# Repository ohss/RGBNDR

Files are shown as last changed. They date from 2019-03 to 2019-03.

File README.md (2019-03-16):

# RGBNDR

RGBNDR is a video synthesiser made by circuit bending a VGA test generator. Inspired by [CHA/V by Jonas Bers](https://jonasbers.com/chav/).

RGBNDR is currently a set of two PCB:s. A board for circuit bending a VGA signal and a board for generating nice signals for bending video. It's a modular design so new boards can be easily added later.

Here's some instructions about how to build one. Schematics, eagle files and gerbers for manufacturing can be found form [https://github.com/ohss/RGBNDR](https://github.com/ohss/RGBNDR)

You can find some examples about what you can do with one on Instagram: [https://www.instagram.com/explore/tags/rgbndr/](https://www.instagram.com/explore/tags/rgbndr/) or you can check out the video below:

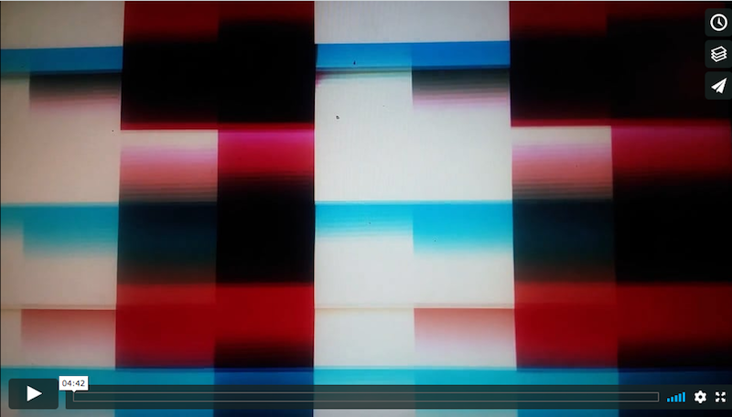
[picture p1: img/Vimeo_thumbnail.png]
RGBNDR Video Synth test on Vimeo (https://vimeo.com/258845977)


# Build it!



You will need to build two boards: RGBNDR board and Modulator board:

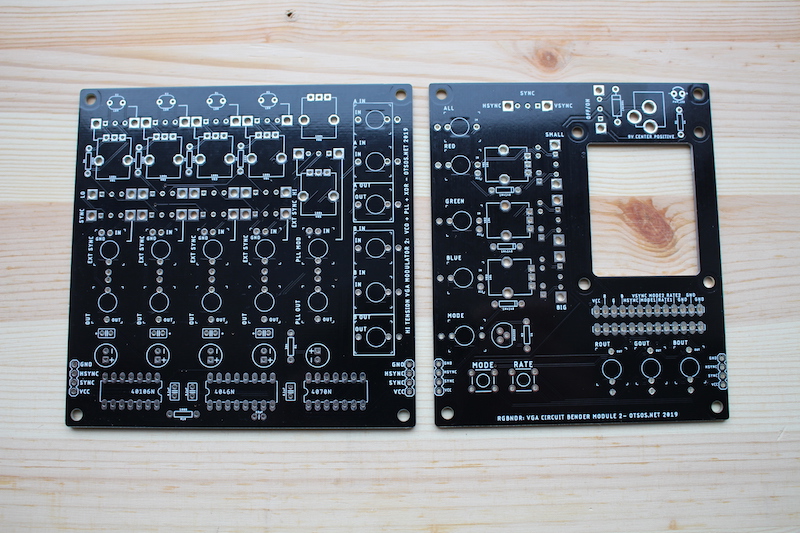
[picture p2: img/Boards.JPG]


Here's a RGBNDR board hooked up to two modulator boards:

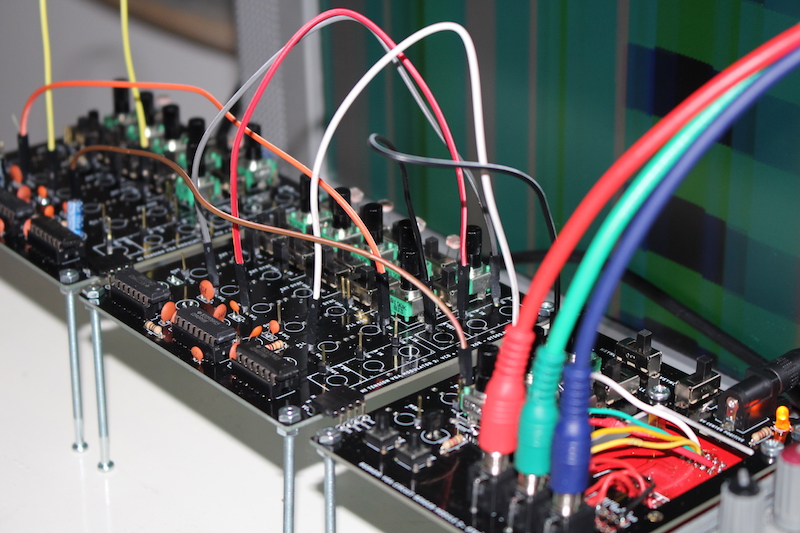
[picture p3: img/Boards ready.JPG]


Here's a quick tip on how to solder:

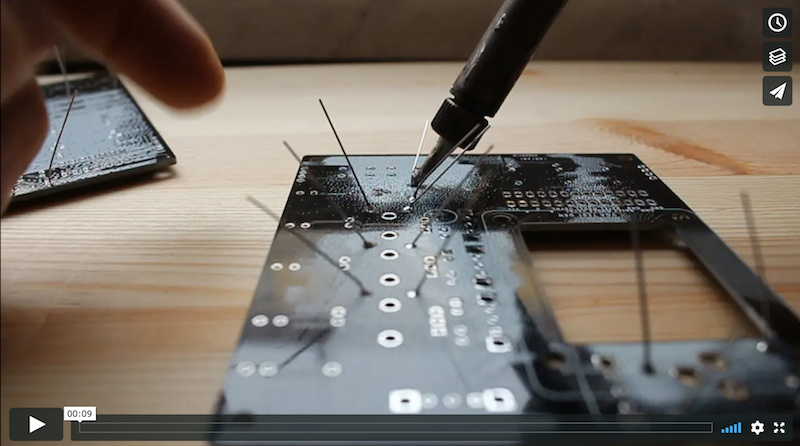
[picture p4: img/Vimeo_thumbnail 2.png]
How to solder (https://vimeo.com/324415428)


## Building RGBNDR (board with VGA test generator)

Here's what you'll need:

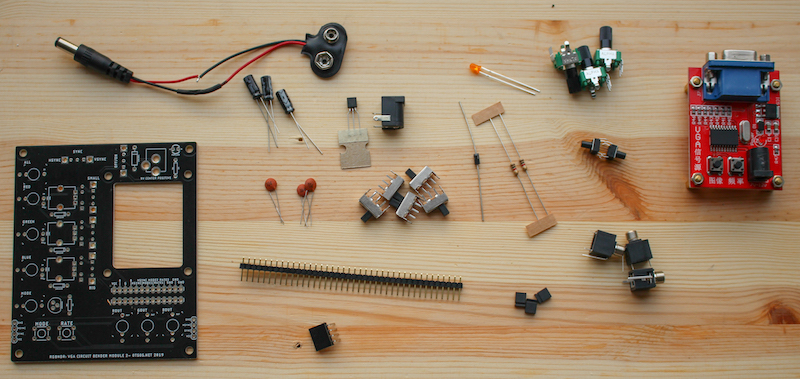
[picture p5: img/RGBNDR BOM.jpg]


| Num | Part | Val | Comment | Link |
|-----|---|-----|---|---|
|2x1|Male pin header||||			
|3x2|Male pin header||||			
|1x4|Female pin header|90° angle|||
|1|Led|3mm|||
|2|Pushbutton|MOMENTARY-SWITCH-SPST-PTH-6.0MM|||
|5|Slide switch|SLIDE SWITCH 1P2T THROUGH HOLE 0.5A 50VDC||https://www.taydaelectronics.com/slide-switch-1p2t-through-hole-0-5a-50vdc-2713.html|
|3|Ceramic capacitor|0.1uF (104)|Try out different values||
|3|Electrolytic capacitor|10uF|Try out different values. Remember polarity!||
|3|Potentiometer|10k|||
|1|Diode|1N4004|||
|3|Jumper wire||PCB has places for 1N4148 diodes. Use jumpers instead.||
|2|Resistor|1k|||
|1|Transistor|2N2222|Check polarity||
|1|Power Jack||V2 revision has a mistace on power. It's cCenter negative NOT center positive ||	
|3|Mono 3.5mm jack|Thonkiconn|Optional|https://www.thonk.co.uk/shop/3-5mm-jacks/|		

Start with adding caps to the bottom side. Remember to check polarity on electrolytic caps!

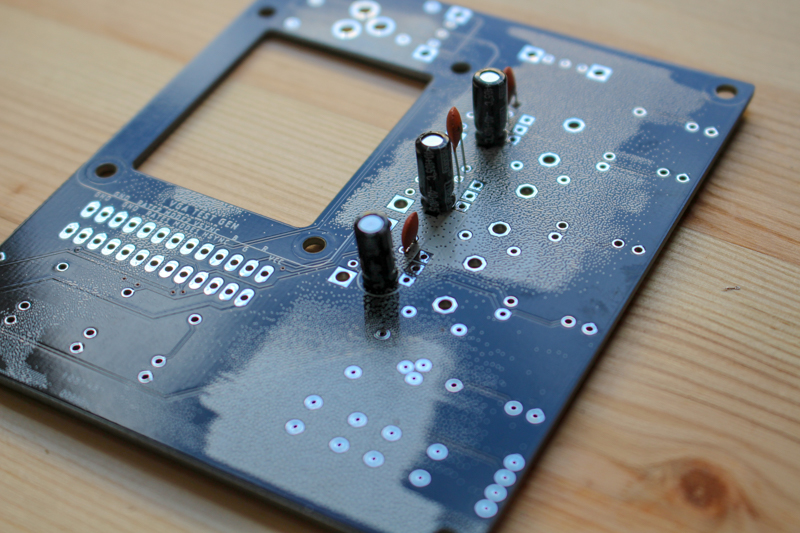
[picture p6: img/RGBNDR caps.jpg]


Use cap legs that you just cut out as jumpers. You'll need three. On the board there is three spots for 1N4148 diode. Use the jumpers instead.

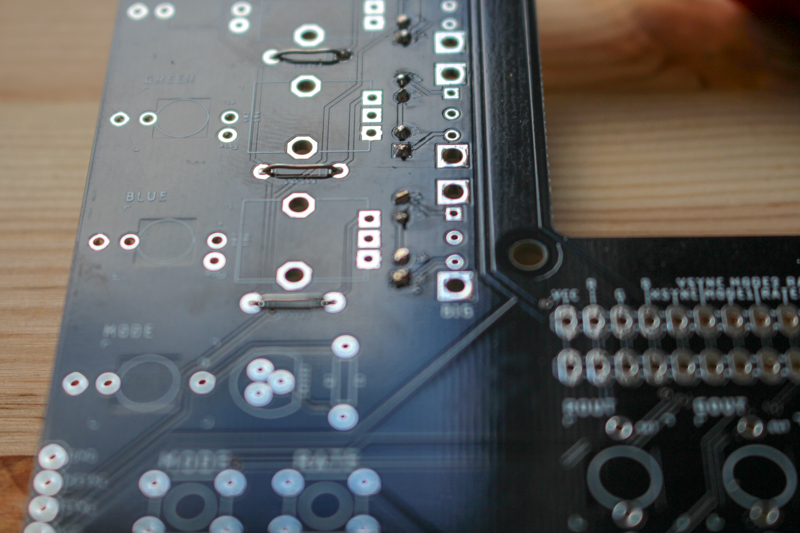
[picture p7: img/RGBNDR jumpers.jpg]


Add two 1k resistors and 1N4004 diode. Remember to check diode polarity!

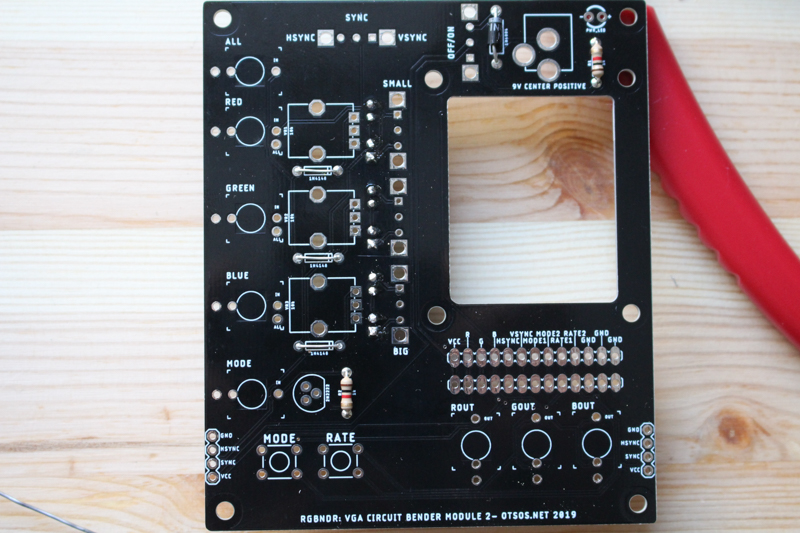
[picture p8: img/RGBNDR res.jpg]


Next one is a bit tricky. You'll need to solder header pins to the board. I like to place the header pins on the board, put a piece on cardboard on top of the pins and then flip the whole thing over with the cardboard keeping the pins where they should be. Usually they fall all over the place.

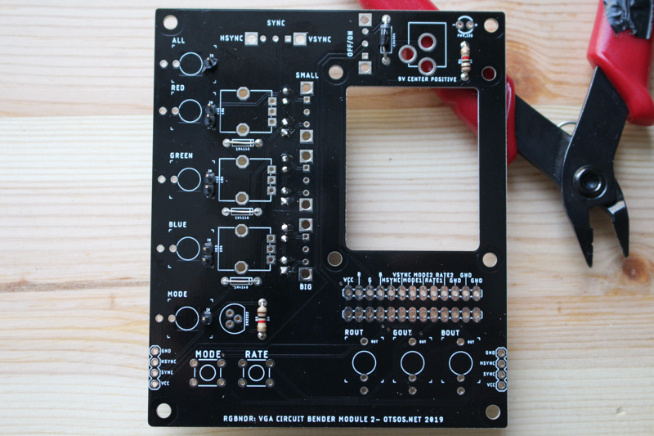
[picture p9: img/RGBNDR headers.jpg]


Then: pushbuttons, transistor (match the flat side to the flat line on the board ) and led. Long leg goes to +.

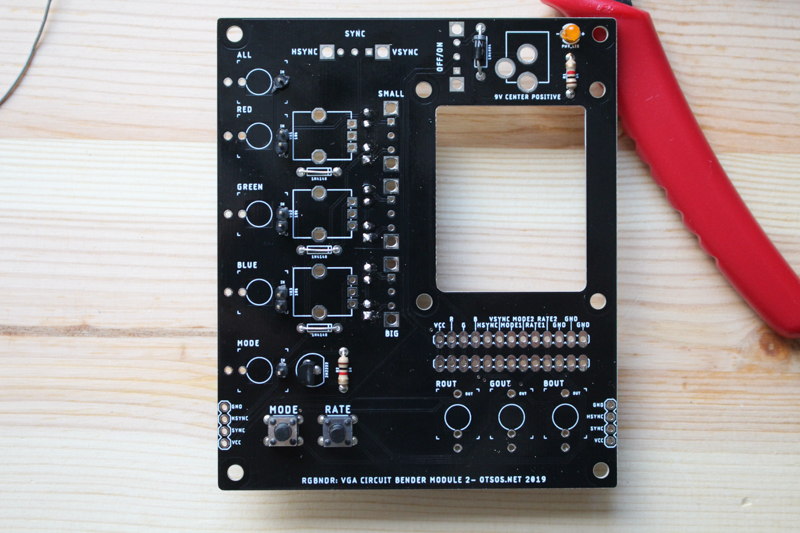
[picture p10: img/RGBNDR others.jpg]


Add female angle header for connecting with other board. Use a helping hand to get the angle header high enough:

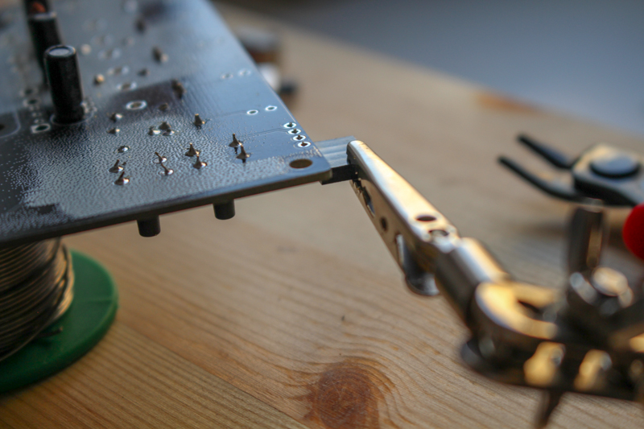
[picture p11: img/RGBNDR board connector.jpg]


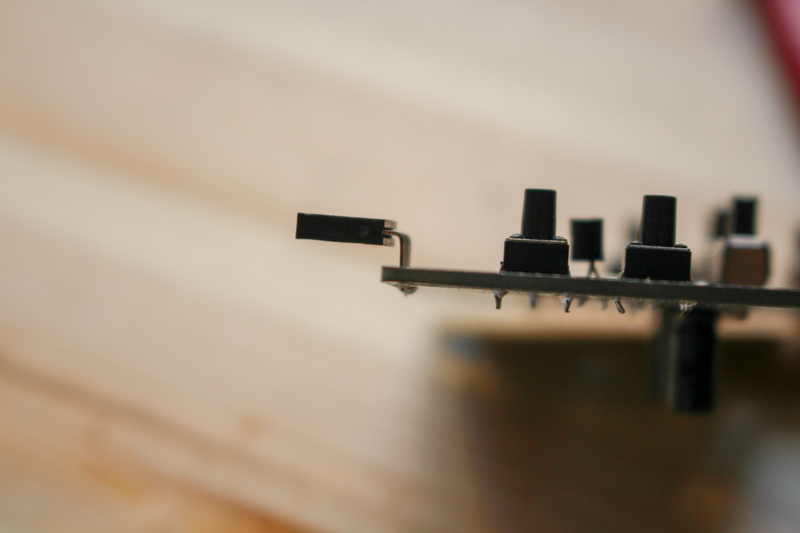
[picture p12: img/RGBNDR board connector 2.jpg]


Add (in this order): 5 slide switches, power connector, three 3.5mm mono jacks, three 10k potentiometers. For pots and slide switches it's ok to solder only the three middle pins.

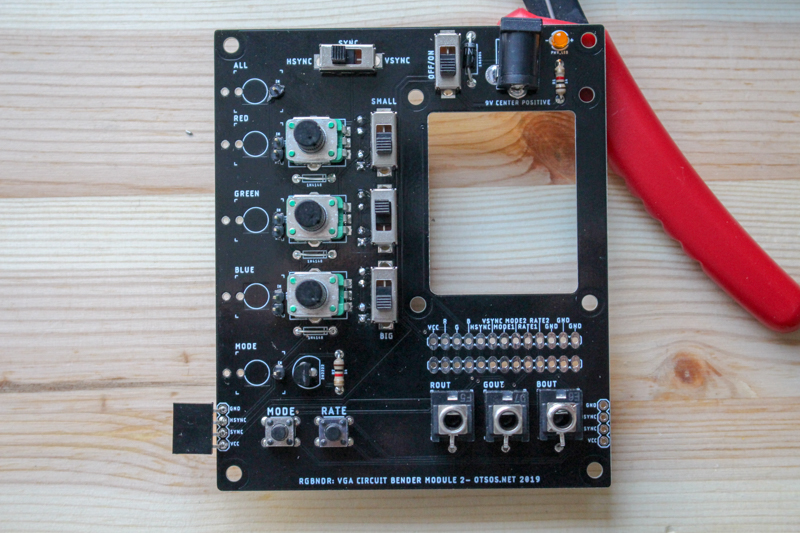
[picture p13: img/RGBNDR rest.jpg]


Solder wires from the test gen board to the RGBNDR board.

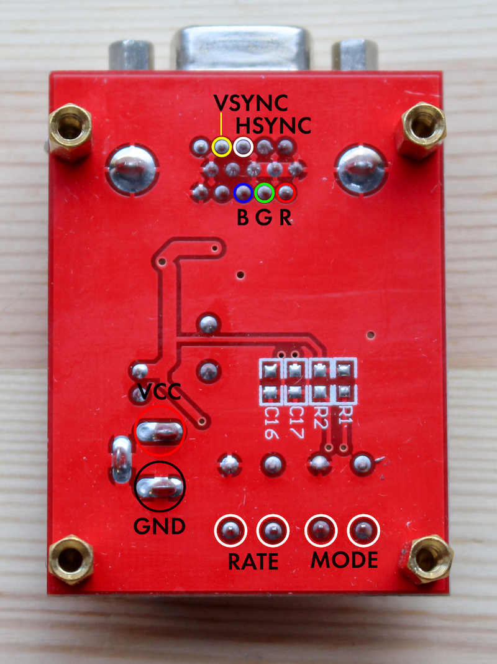
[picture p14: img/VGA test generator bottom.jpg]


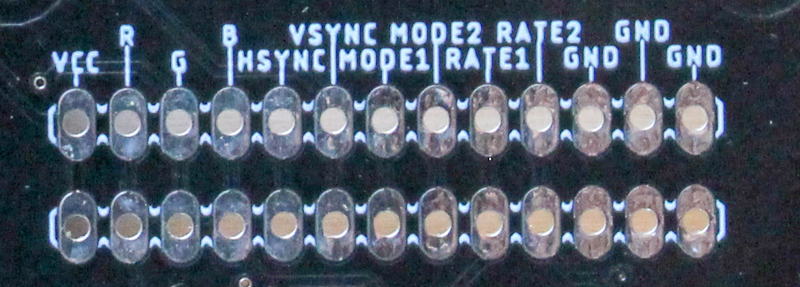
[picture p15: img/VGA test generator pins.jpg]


Done!

## Building modulator board

Here's what you'll need:

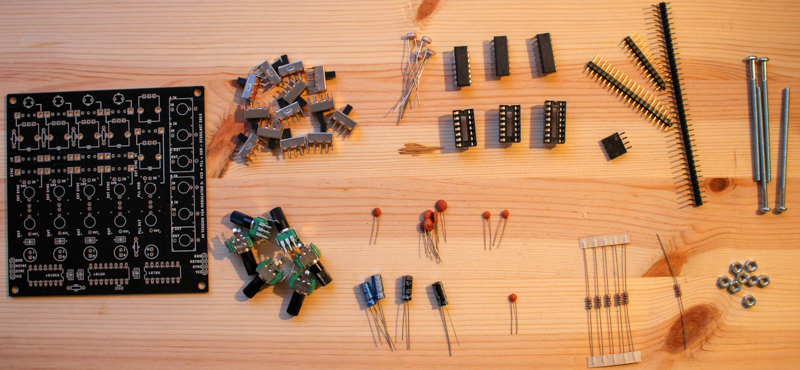
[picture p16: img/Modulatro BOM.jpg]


| Num | Part | Val | Comment | Link |
|-----|---|-----|---|---|
|11x1|Male pin header||||			
|5x2|Male pin header||||			
|1x4|Male pin header|90° angle|||
|4|LDR||Optional||
|13|Slide switch|SLIDE SWITCH 1P2T THROUGH HOLE 0.5A 50VDC|If you don't use LDRs, replace switch with jumper|https://www.taydaelectronics.com/slide-switch-1p2t-through-hole-0-5a-50vdc-2713.html|
|1|Ceramic capacitor|22pF||||
|1|Ceramic capacitor|0.001uF (102)|||
|2|Ceramic capacitor|0.01uF (103)|||
|5|Ceramic capacitor|0.1uF (104)|||
|2|Electrolytic capacitor|100uF|Remember polarity!||
|1|Electrolytic capacitor|10uF|Remember polarity!||
|1|Electrolytic capacitor|1uF|Remember polarity!||
|6|Potentiometer|100k|||
|1|Resistor|20k|||
|5|Resistor|100R|||
|1|IC|40106|||
|1|IC|4046|||
|1|IC|4070|||

Start with the flattest parts so that soldering is as easy as possible. So:

1. Resistors
2. ICs
3. Header pins
4. Caps
5. Switches
6. LDRs
7. Pots

Few tips:

Use IC sockets and align them correctly. I made a mistake on the photo:

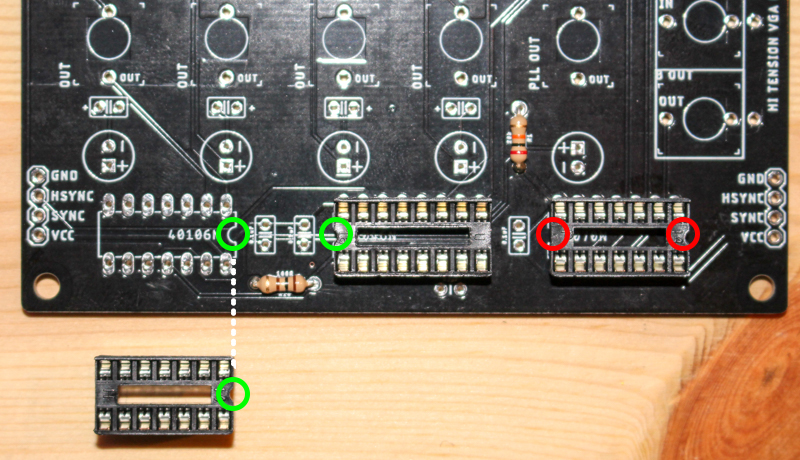
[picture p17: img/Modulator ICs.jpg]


You can chose what ever values for oscillator caps you want. Together with a potentiometer these will define frequency for an oscillator. For each oscillator you can pick big and small cap and change between those with a switch.

My setup is like this but try your own values!

| |OSC 1|OSC 2|OSC 3|OSC 4|4046 MOD|
|-----|-----|-----|-----|-----|---|
|SMALL|10nF|0.1nF|0.01nF|0.001nf| - |
| BIG |100nF|1nF|0.1nF|0.01nF|100nF|

I put the big caps on the bottom side.

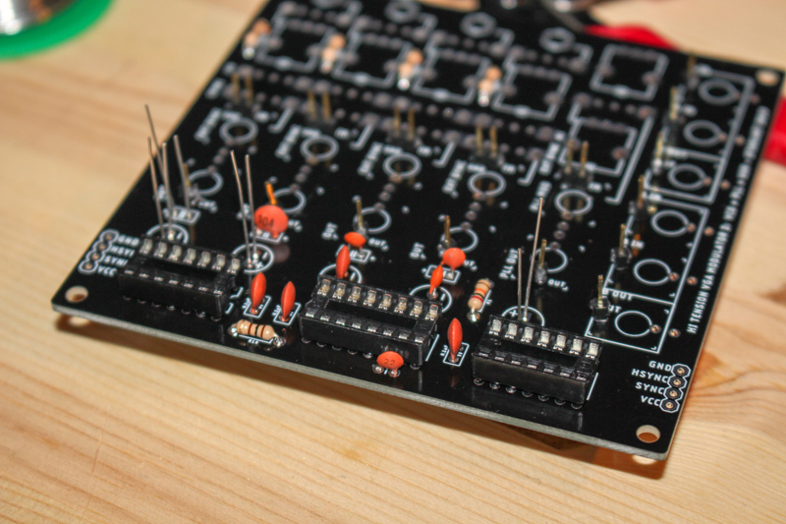
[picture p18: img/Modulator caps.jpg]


After some soldering it should look more or less like this:

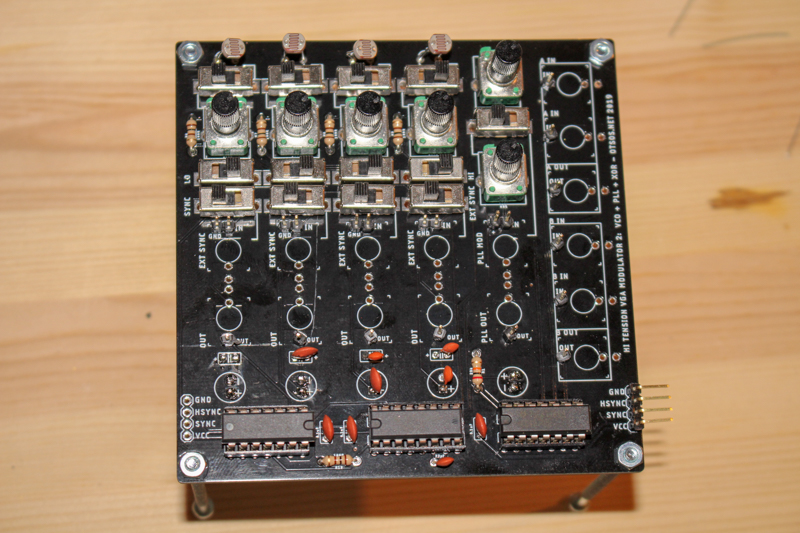
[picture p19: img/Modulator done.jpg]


Hook it up with RGBNDR and that's it!

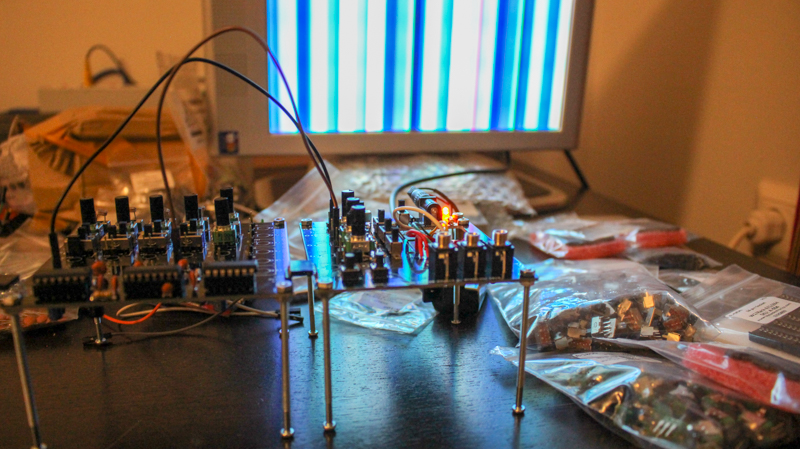
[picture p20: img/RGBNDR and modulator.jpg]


Later you can make a box for it. Here's an older version with jacks:

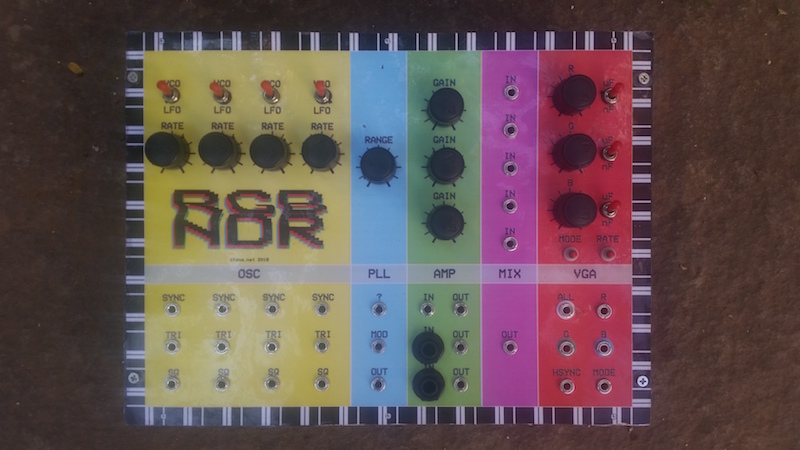
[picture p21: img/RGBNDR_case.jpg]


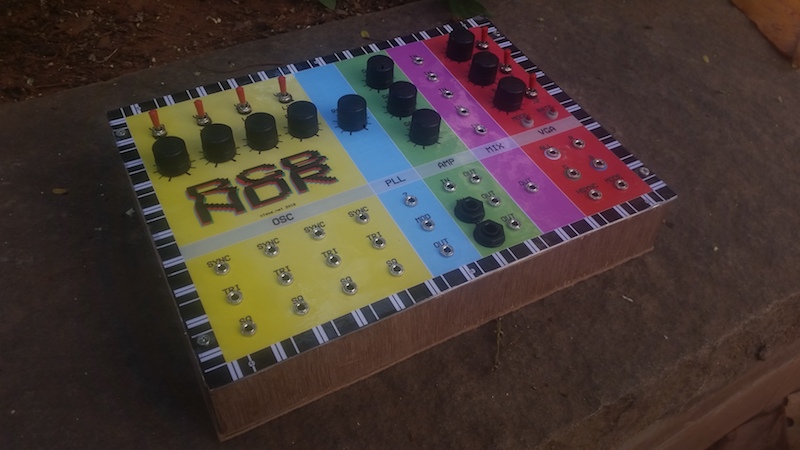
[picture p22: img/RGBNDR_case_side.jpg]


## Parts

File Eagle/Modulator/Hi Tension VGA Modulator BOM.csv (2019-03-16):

Qty | Value | Device | Package | Parts | Description | AVAILABILITY | DESCRIPTION | MF | MP | PACKAGE | PRICE | PROD_ID | SF_ID | SF_SKU | SPICEPREFIX | VALUE
5 |  | CONN_01PTH_NO_SILK_YES_STOP | 1X01_NO_SILK | J3, J4, J5, J6, J7 | Single connection point. Often used as Generic Header-pin footprint for 0.1 inch spaced/style header connections
2 |  | CONN_04 | 1X04 | J1, J8 | Multi connection point. Often used as Generic Header-pin footprint for 0.1 inch spaced/style header connections |  |  |  |  |  |  | CONN-09696
13 |  | OS102011MS2QN1 | SW_OS102011MS2QN1 | S1, S2, S3, S4, S5, S6, S7, S8, S9, S10, S11, S12, S13 | Switch Slide ON ON SPDT Top Slide 0.1A 12VDC 10000Cycles PC Pins Thru-Hole Bulk | Unavailable | Switch Slide ON ON SPDT Top Slide 0.1A 12VDC 10000Cycles PC Pins Thru-Hole Bulk | C&K | OS102011MS2QN1 | DO-201 C&amp | K Components | None
7 | 0.1uF | C-EU025-025X050 | C025-025X050 | C2, C4, C6, C8, C9, C12, C13 | CAPACITOR, European symbol |  |  |  |  |  |  |  |  |  | C
5 | 100R | 1KOHM-HORIZ-1/4W-1% | AXIAL-0.3 | R6, R7, R8, R9, R10 | 1kΩ resistor |  |  |  |  |  |  | RES-12182 |  |  |  | 1k
6 | 100k | POTENTIOMETER-PTH-9MM-1/20W-20% | POT-PTH-ALPS | VR1, VR2, VR3, VR4, VR5, VR6 | Potentiometer (Pot) |  |  |  |  |  |  | RES-09177 |  | COM-09288 |  | 10k
5 | 100uF | 100UF-POLAR-RADIAL-2.5MM-25V-20% | CPOL-RADIAL-2.5MM-6.5MM | C1, C3, C5, C7, C10 | 100µF polarized capacitors |  |  |  |  |  |  | CAP-08439 |  |  |  | 100uF
1 | 20k | 1KOHM-HORIZ-1/4W-1% | AXIAL-0.3 | R1 | 1kΩ resistor |  |  |  |  |  |  | RES-12182 |  |  |  | 1k
1 | 22pF | 22PF-PTH-2.54MM-200V-5% | CAP-PTH-2.54 | C11 | 22pF ceramic capacitors |  |  |  |  |  |  | CAP-09128 |  |  |  | 22pF
1 | 40106N | 40106N | DIL14 | IC1 | Hex SCHMITT TRIGGER
1 | 4046N | 4046N | DIL16 | IC2 | Micropower PLL
1 | 4070N | 4070N | DIL14 | IC3 | Quad 2-input XOR
4 | LDR | PHOTOCELLPTH | PHOTOCELL | R2, R3, R4, R5 | Photocell (Photodetector, Photo Resistor, CdS) |  |  |  |  |  |  | COMP-09129 | SEN-09088
16 | THONKICONNNEW | THONKICONNNEW | WQP-PJ301M-12_JACK | OSC1_OUT, OSC1_SYNC, OSC2_OUT, OSC2_SYNC, OSC3_OUT, OSC3_SYNC, OSC4_OUT, OSC4_SYNC, PLL_MOD, PLL_OUT, XOR_IN_1, XOR_IN_2, XOR_IN_3, XOR_IN_4, XOR_OUT_1, XOR_OUT_2 | 3.5mm socket for Eurorack modular synths

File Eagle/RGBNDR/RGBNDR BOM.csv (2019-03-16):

Qty | Value | Device | Package | Parts | Description | AVAILABILITY | DESCRIPTION | MF | MP | PACKAGE | PRICE | PROD_ID | SF_SKU | SPICEPREFIX | VALUE
3 |  | CONN_01PTH_NO_SILK_YES_STOP | 1X01_NO_SILK | ALL_J1, ALL_J2, ALL_J3 | Single connection point. Often used as Generic Header-pin footprint for 0.1 inch spaced/style header connections
2 |  | CONN_04 | 1X04 | J3, J6 | Multi connection point. Often used as Generic Header-pin footprint for 0.1 inch spaced/style header connections |  |  |  |  |  |  | CONN-09696
2 |  | CONN_13LONGPADS | 1X13-LONGPADS | J1, J2 | Multi connection point. Often used as Generic Header-pin footprint for 0.1 inch spaced/style header connections
1 |  | LED3MM | LED_3MM | PWR_LED | LED (Generic) |  |  |  |  |  |  | DIO-08794
2 |  | MOMENTARY-SWITCH-SPST-PTH-6.0MM | TACTILE_SWITCH_PTH_6.0MM | MODE_BTN, RATE_BTN | Momentary Switch (Pushbutton) - SPST |  |  |  |  |  |  | SWCH-08441 | COM-00097
5 |  | OS102011MS2QN1 | SW_OS102011MS2QN1 | OFF/ON, S1, S2, S3, S4 | Switch Slide ON ON SPDT Top Slide 0.1A 12VDC 10000Cycles PC Pins Thru-Hole Bulk | Unavailable | Switch Slide ON ON SPDT Top Slide 0.1A 12VDC 10000Cycles PC Pins Thru-Hole Bulk | C&K | OS102011MS2QN1 | DO-201 C&amp | K Components | None
3 | 0.1uF | C-EU025-025X050 | C025-025X050 | C1, C3, C5 | CAPACITOR, European symbol |  |  |  |  |  |  |  |  | C
3 | 100uF | 100UF-POLAR-RADIAL-2.5MM-25V-20% | CPOL-RADIAL-2.5MM-6.5MM | C2, C4, C6 | 100µF polarized capacitors |  |  |  |  |  |  | CAP-08439 |  |  | 100uF
3 | 10k | POTENTIOMETER-PTH-9MM-1/20W-20% | POT-PTH-ALPS | VR1, VR2, VR3 | Potentiometer (Pot) |  |  |  |  |  |  | RES-09177 | COM-09288 |  | 10k
1 | 1N4004 | DIODE-PTH | DIODE-1N4001 | D1 | Diode |  |  |  |  |  |  | DIO-09176 |  |  | 1A/50V/1.1V
3 | 1N4148 | DIODE-1N4148 | DIODE-1N4148 | D2, D3, D4 | Diode |  |  |  |  |  |  | DIO-08378 |  |  | 200mA/100V/1V
2 | 1k | 1KOHM-HORIZ-1/4W-1% | AXIAL-0.3 | R1, R2 | 1kΩ resistor |  |  |  |  |  |  | RES-12182 |  |  | 1k
1 | 2N2222 | TRANS_NPN-2N3904 | TO-92 | Q1 | NPN transistor |  |  |  |  |  |  | TRANS-08447 |  |  | 200mA/40V
1 | POWER_JACK | POWER_JACK | POWER_JACK_PTH | J4 | Power Jack Connector |  |  |  |  |  |  | CONN-08197
8 | THONKICONNNEW | THONKICONNNEW | WQP-PJ301M-12_JACK | ALL, BLUE, BOUT, GOUT, GREEN, MODE, RED, ROUT | 3.5mm socket for Eurorack modular synths

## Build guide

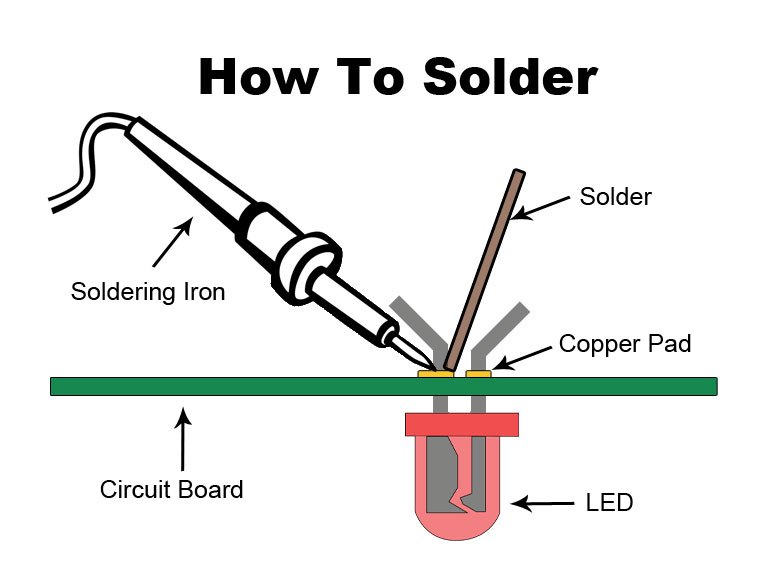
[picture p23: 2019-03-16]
img/how-to-solder.jpg

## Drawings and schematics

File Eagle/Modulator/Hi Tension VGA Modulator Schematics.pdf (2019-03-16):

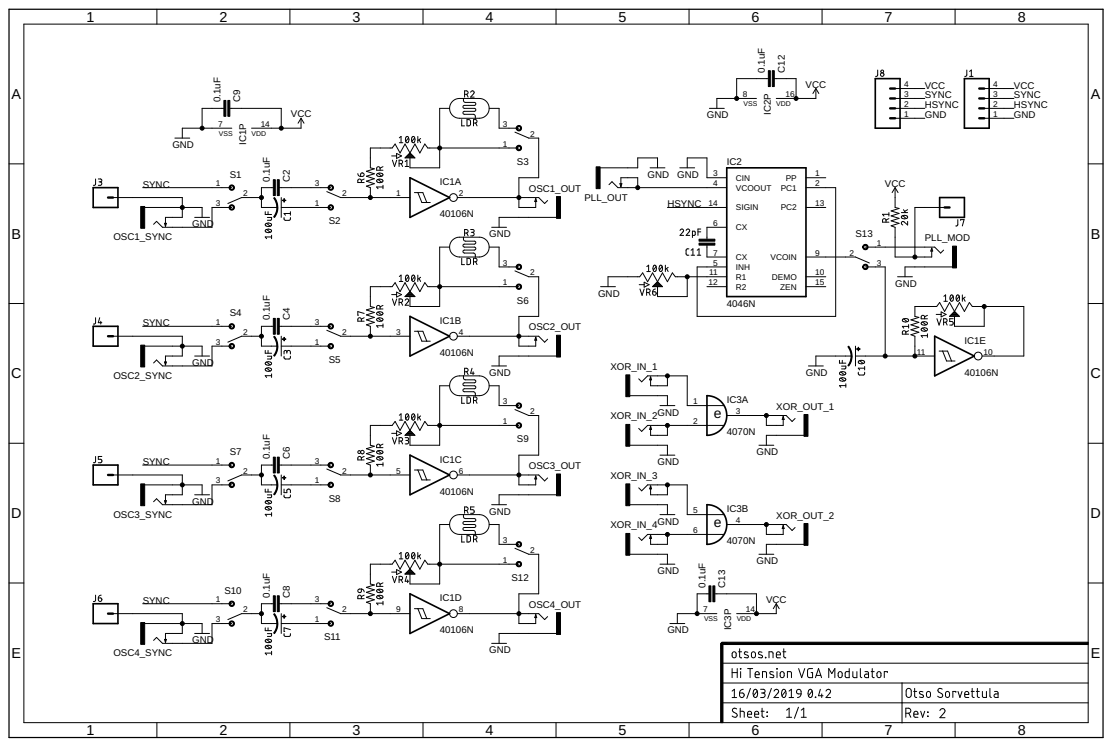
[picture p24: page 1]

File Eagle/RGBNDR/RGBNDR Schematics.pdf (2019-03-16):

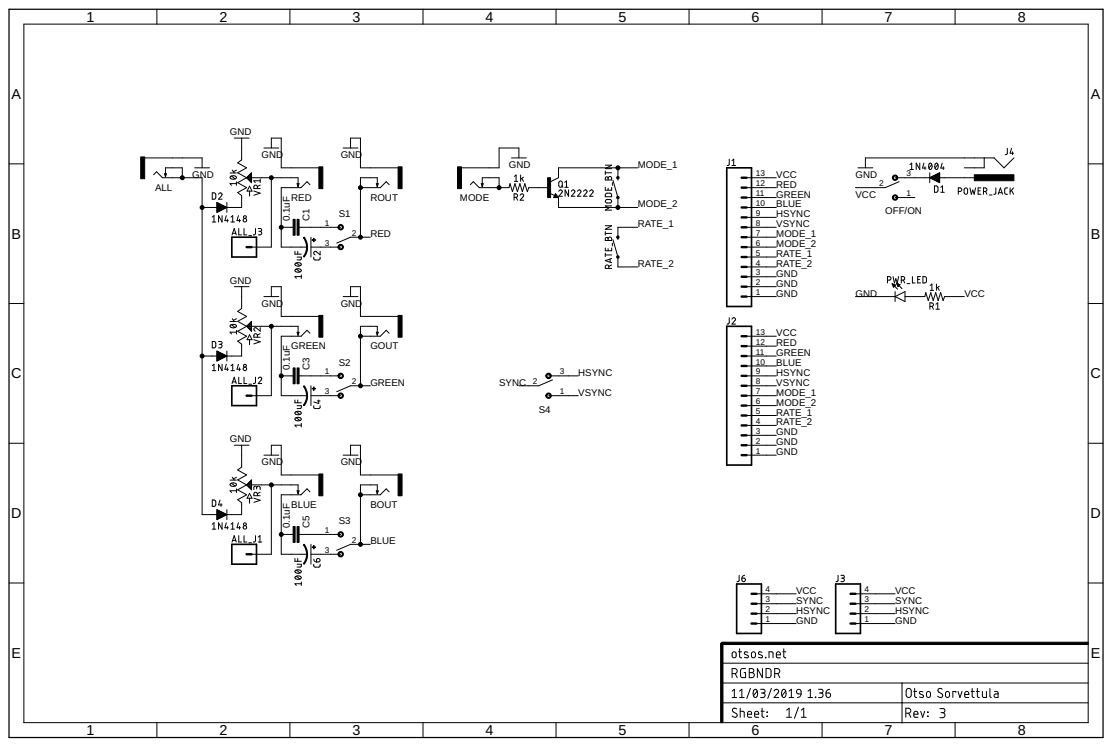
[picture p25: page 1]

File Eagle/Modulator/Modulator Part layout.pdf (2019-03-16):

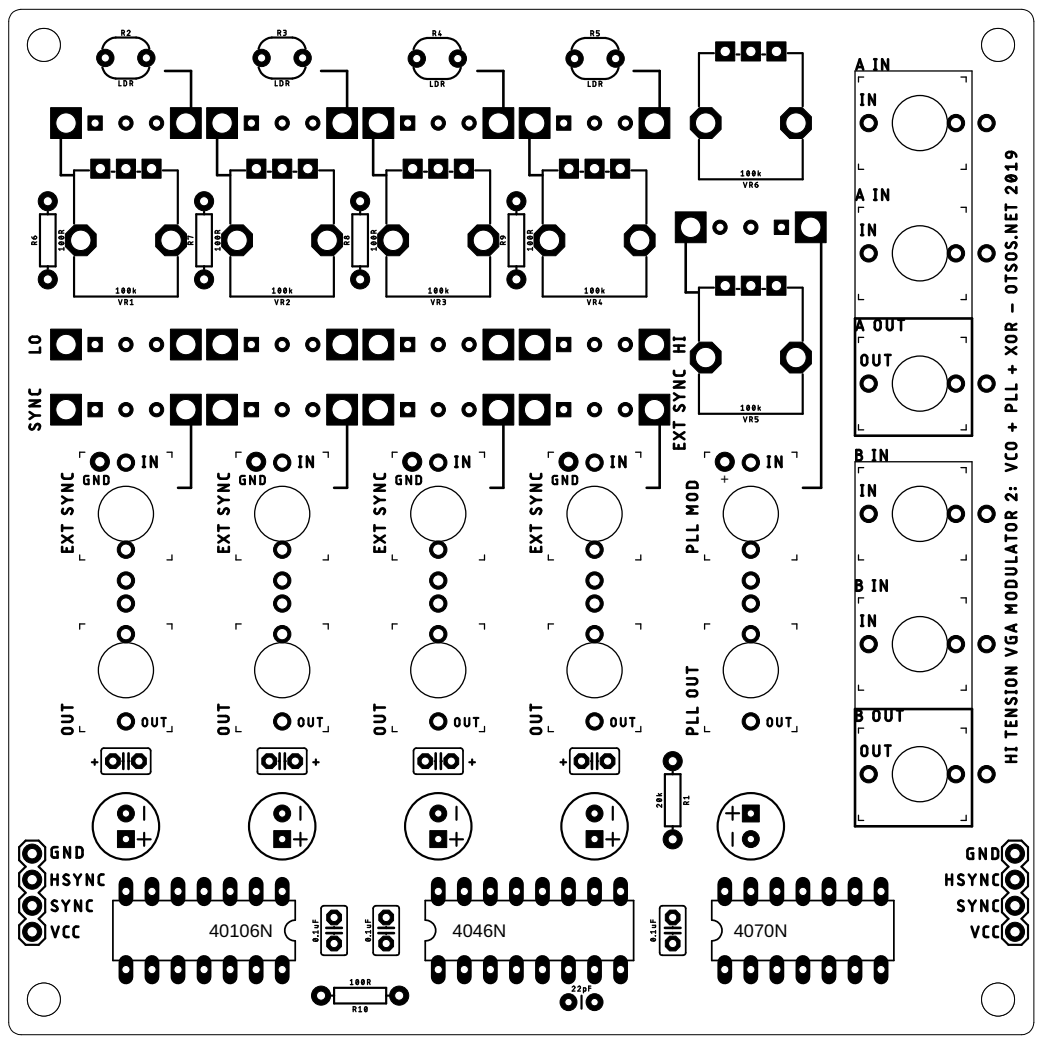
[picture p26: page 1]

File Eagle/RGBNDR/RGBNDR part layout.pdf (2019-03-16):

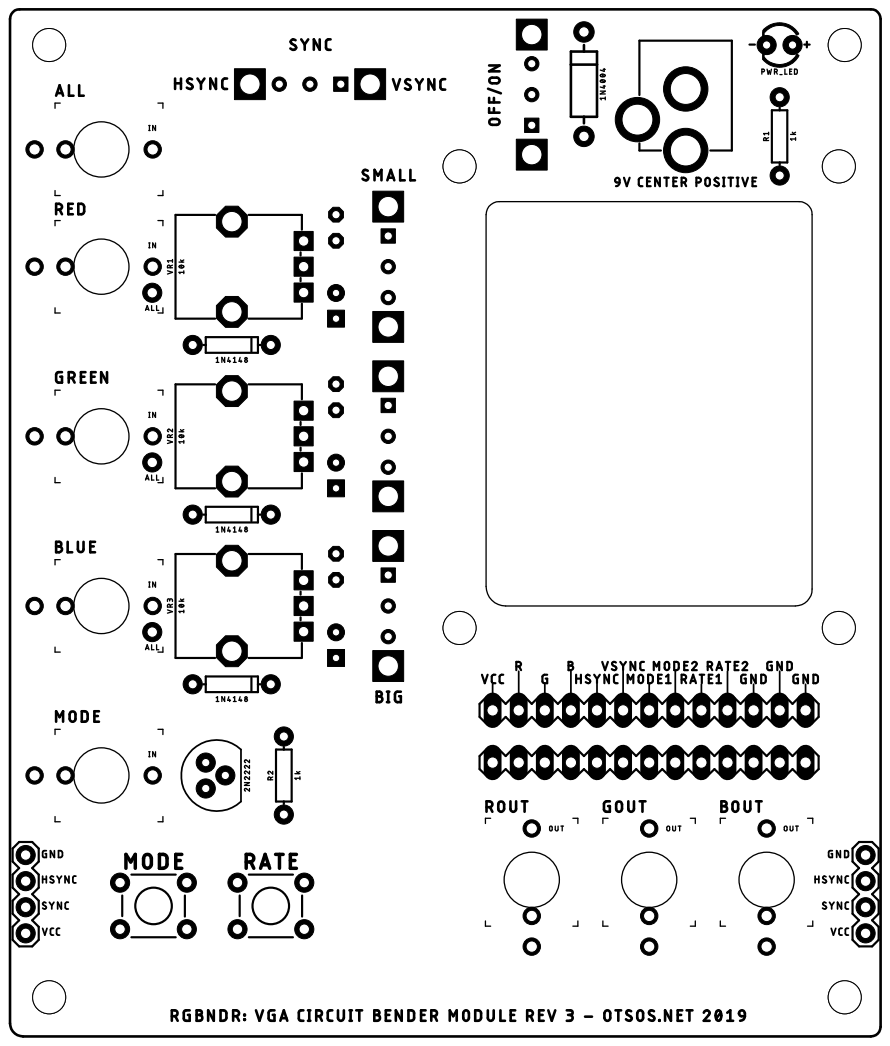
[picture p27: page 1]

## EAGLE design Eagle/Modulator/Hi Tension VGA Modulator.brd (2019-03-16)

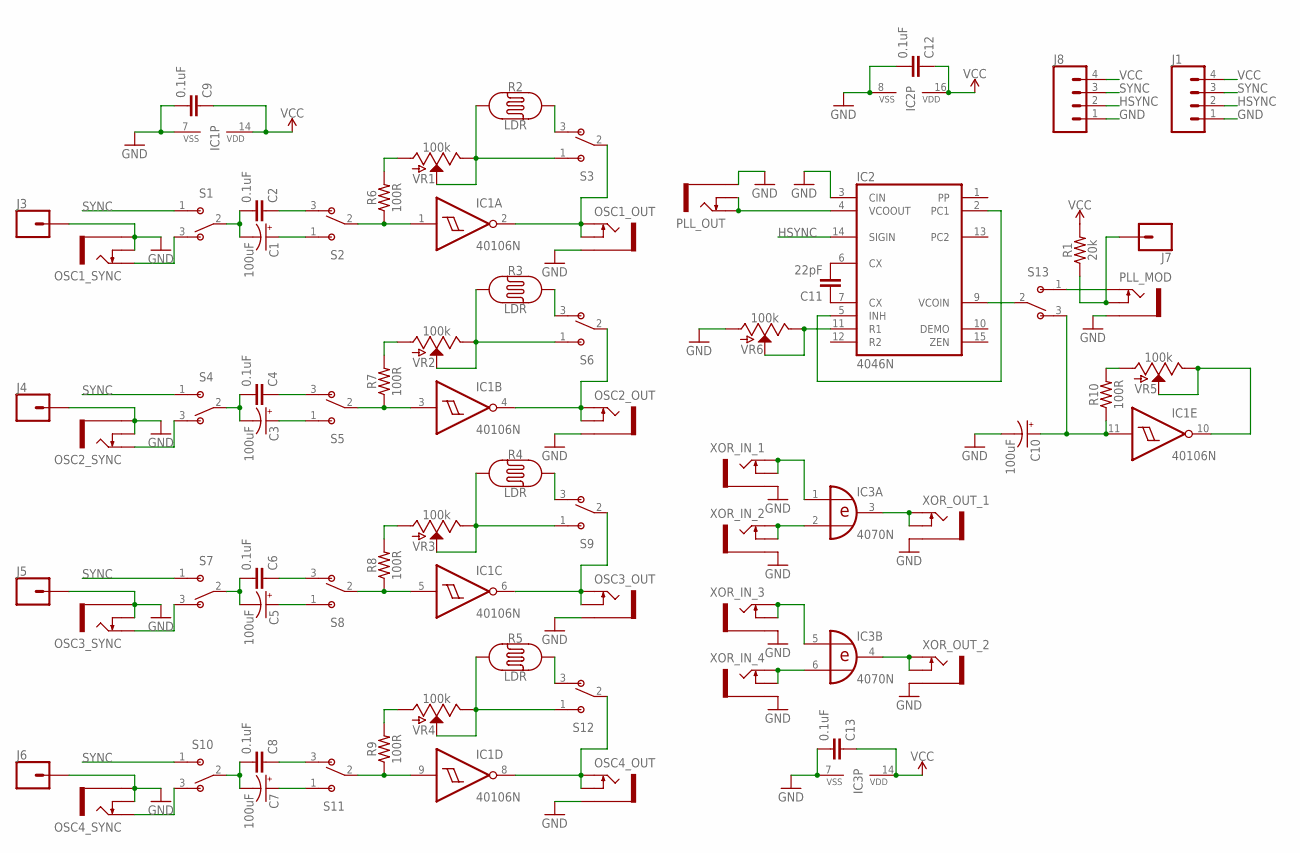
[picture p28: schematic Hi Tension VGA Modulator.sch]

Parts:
C1, C3, C5, C7, C10: 100uF; CPOL-RADIAL-2.5MM-6.5MM
C2, C4, C6, C8, C9, C12, C13: 0.1uF; C025-025X050
C11: 22pF; CAP-PTH-2.54
IC1: 40106N; DIL14
IC2: 4046N; DIL16
IC3: 4070N; DIL14
J1, J8: CONN_04; 1X04
J3, J4, J5, J6, J7: CONN_01PTH_NO_SILK_YES_STOP; 1X01_NO_SILK
OSC1_OUT, OSC1_SYNC, OSC2_OUT, OSC2_SYNC, OSC3_OUT, OSC3_SYNC, OSC4_OUT, OSC4_SYNC: THONKICONNNEW; WQP-PJ301M-12_JACK
PLL_MOD: THONKICONNNEW; WQP-PJ301M-12_JACK
PLL_OUT: THONKICONNNEW; WQP-PJ301M-12_JACK
R1: 20k; AXIAL-0.3
R2, R3, R4, R5: LDR; PHOTOCELL
R6, R7, R8, R9, R10: 100R; AXIAL-0.3
S1, S2, S3, S4, S5, S6, S7, S8, S9, S10, S11, S12, S13: OS102011MS2QN1; SW_OS102011MS2QN1
VR1, VR2, VR3, VR4, VR5, VR6: 100k; POT-PTH-ALPS
XOR_IN_1, XOR_IN_2, XOR_IN_3, XOR_IN_4: THONKICONNNEW; WQP-PJ301M-12_JACK
XOR_OUT_1, XOR_OUT_2: THONKICONNNEW; WQP-PJ301M-12_JACK

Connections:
GND: C9.2, C10.2 (-), C12.2, C13.2, IC1.7 (VSS), IC2.3 (CIN), IC2.8 (VSS), IC3.7 (VSS), J1.1, J3.1, J4.1, J5.1, J6.1, J8.1, OSC1_OUT.P$3_SLEEVE (SLEEVE), OSC1_SYNC.P$2_SWITCH (SWITCH), OSC1_SYNC.P$3_SLEEVE (SLEEVE), OSC2_OUT.P$3_SLEEVE (SLEEVE), OSC2_SYNC.P$2_SWITCH (SWITCH), OSC2_SYNC.P$3_SLEEVE (SLEEVE), OSC3_OUT.P$3_SLEEVE (SLEEVE), OSC3_SYNC.P$2_SWITCH (SWITCH), OSC3_SYNC.P$3_SLEEVE (SLEEVE), OSC4_OUT.P$3_SLEEVE (SLEEVE), OSC4_SYNC.P$2_SWITCH (SWITCH), OSC4_SYNC.P$3_SLEEVE (SLEEVE), PLL_MOD.P$3_SLEEVE (SLEEVE), PLL_OUT.P$3_SLEEVE (SLEEVE), VR6.P$3 (A), XOR_IN_1.P$3_SLEEVE (SLEEVE), XOR_IN_2.P$3_SLEEVE (SLEEVE), XOR_IN_3.P$3_SLEEVE (SLEEVE), XOR_IN_4.P$3_SLEEVE (SLEEVE), XOR_OUT_1.P$3_SLEEVE (SLEEVE), XOR_OUT_2.P$3_SLEEVE (SLEEVE)
HSYNC: IC2.14 (SIGIN), J1.2, J8.2
unnamed: OSC1_SYNC.P$1_TIP (TIP), S1.3
unnamed: C1.2 (-), C2.2, S1.2
unnamed: C2.1, S2.3
unnamed: C1.1 (+), S2.1
unnamed: IC1.1 (I), R6.P$1 (1), S2.2
unnamed: R10.P$2 (2), VR5.P$3 (A)
unnamed: R2.1, S3.1, VR1.P$1 (E), VR1.P$2 (S)
unnamed: IC1.2 (O), OSC1_OUT.P$1_TIP (TIP), OSC1_OUT.P$2_SWITCH (SWITCH), S3.2
unnamed: OSC2_SYNC.P$1_TIP (TIP), S4.3
unnamed: C3.2 (-), C4.2, S4.2
unnamed: C3.1 (+), S5.1
unnamed: IC1.3 (I), R7.P$1 (1), S5.2
unnamed: R2.2, S3.3
unnamed: IC1.4 (O), OSC2_OUT.P$1_TIP (TIP), OSC2_OUT.P$2_SWITCH (SWITCH), S6.2
unnamed: C4.1, S5.3
unnamed: OSC3_SYNC.P$1_TIP (TIP), S7.3
unnamed: C5.2 (-), C6.2, S7.2
unnamed: C5.1 (+), S8.1
unnamed: IC1.5 (I), R8.P$1 (1), S8.2
unnamed: R3.2, S6.3
unnamed: R5.2, S12.3
unnamed: IC1.6 (O), OSC3_OUT.P$1_TIP (TIP), OSC3_OUT.P$2_SWITCH (SWITCH), S9.2
unnamed: C6.1, S8.3
unnamed: OSC4_SYNC.P$1_TIP (TIP), S10.3
unnamed: C7.2 (-), C8.2, S10.2
unnamed: C8.1, S11.3
unnamed: IC1.9 (I), R9.P$1 (1), S11.2
unnamed: R4.1, S9.1, VR3.P$1 (E), VR3.P$2 (S)
unnamed: IC1.8 (O), OSC4_OUT.P$1_TIP (TIP), OSC4_OUT.P$2_SWITCH (SWITCH), S12.2
unnamed: C7.1 (+), S11.1
unnamed: C11.1, IC2.7 (CX)
unnamed: C11.2, IC2.6 (CX)
unnamed: IC2.9 (VCOIN), S13.2
unnamed: PLL_MOD.P$1_TIP (TIP), S13.1
unnamed: IC2.2 (PC1), IC2.5 (INH)
unnamed: IC2.4 (VCOOUT), PLL_OUT.P$1_TIP (TIP), PLL_OUT.P$2_SWITCH (SWITCH)
unnamed: J7.1, PLL_MOD.P$2_SWITCH (SWITCH), R1.P$1 (1)
unnamed: C10.1 (+), IC1.11 (I), R10.P$1 (1), S13.3
unnamed: IC1.10 (O), VR5.P$1 (E), VR5.P$2 (S)
unnamed: IC3.5 (I0), XOR_IN_3.P$1_TIP (TIP), XOR_IN_3.P$2_SWITCH (SWITCH)
unnamed: IC2.11 (R1), VR6.P$1 (E), VR6.P$2 (S)
unnamed: IC3.1 (I0), XOR_IN_1.P$1_TIP (TIP), XOR_IN_1.P$2_SWITCH (SWITCH)
unnamed: IC3.2 (I1), XOR_IN_2.P$1_TIP (TIP), XOR_IN_2.P$2_SWITCH (SWITCH)
unnamed: IC3.6 (I1), XOR_IN_4.P$1_TIP (TIP), XOR_IN_4.P$2_SWITCH (SWITCH)
unnamed: IC3.3 (O), XOR_OUT_1.P$1_TIP (TIP), XOR_OUT_1.P$2_SWITCH (SWITCH)
unnamed: IC3.4 (O), XOR_OUT_2.P$1_TIP (TIP), XOR_OUT_2.P$2_SWITCH (SWITCH)
unnamed: R4.2, S9.3
unnamed: R3.1, S6.1, VR2.P$1 (E), VR2.P$2 (S)
unnamed: R5.1, S12.1, VR4.P$1 (E), VR4.P$2 (S)
unnamed: R6.P$2 (2), VR1.P$3 (A)
unnamed: R7.P$2 (2), VR2.P$3 (A)
unnamed: R8.P$2 (2), VR3.P$3 (A)
unnamed: R9.P$2 (2), VR4.P$3 (A)
SYNC: J1.3, J8.3, S1.1, S4.1, S7.1, S10.1
VCC: C9.1, C12.1, C13.1, IC1.14 (VDD), IC2.16 (VDD), IC3.14 (VDD), J1.4, J8.4, R1.P$2 (2)

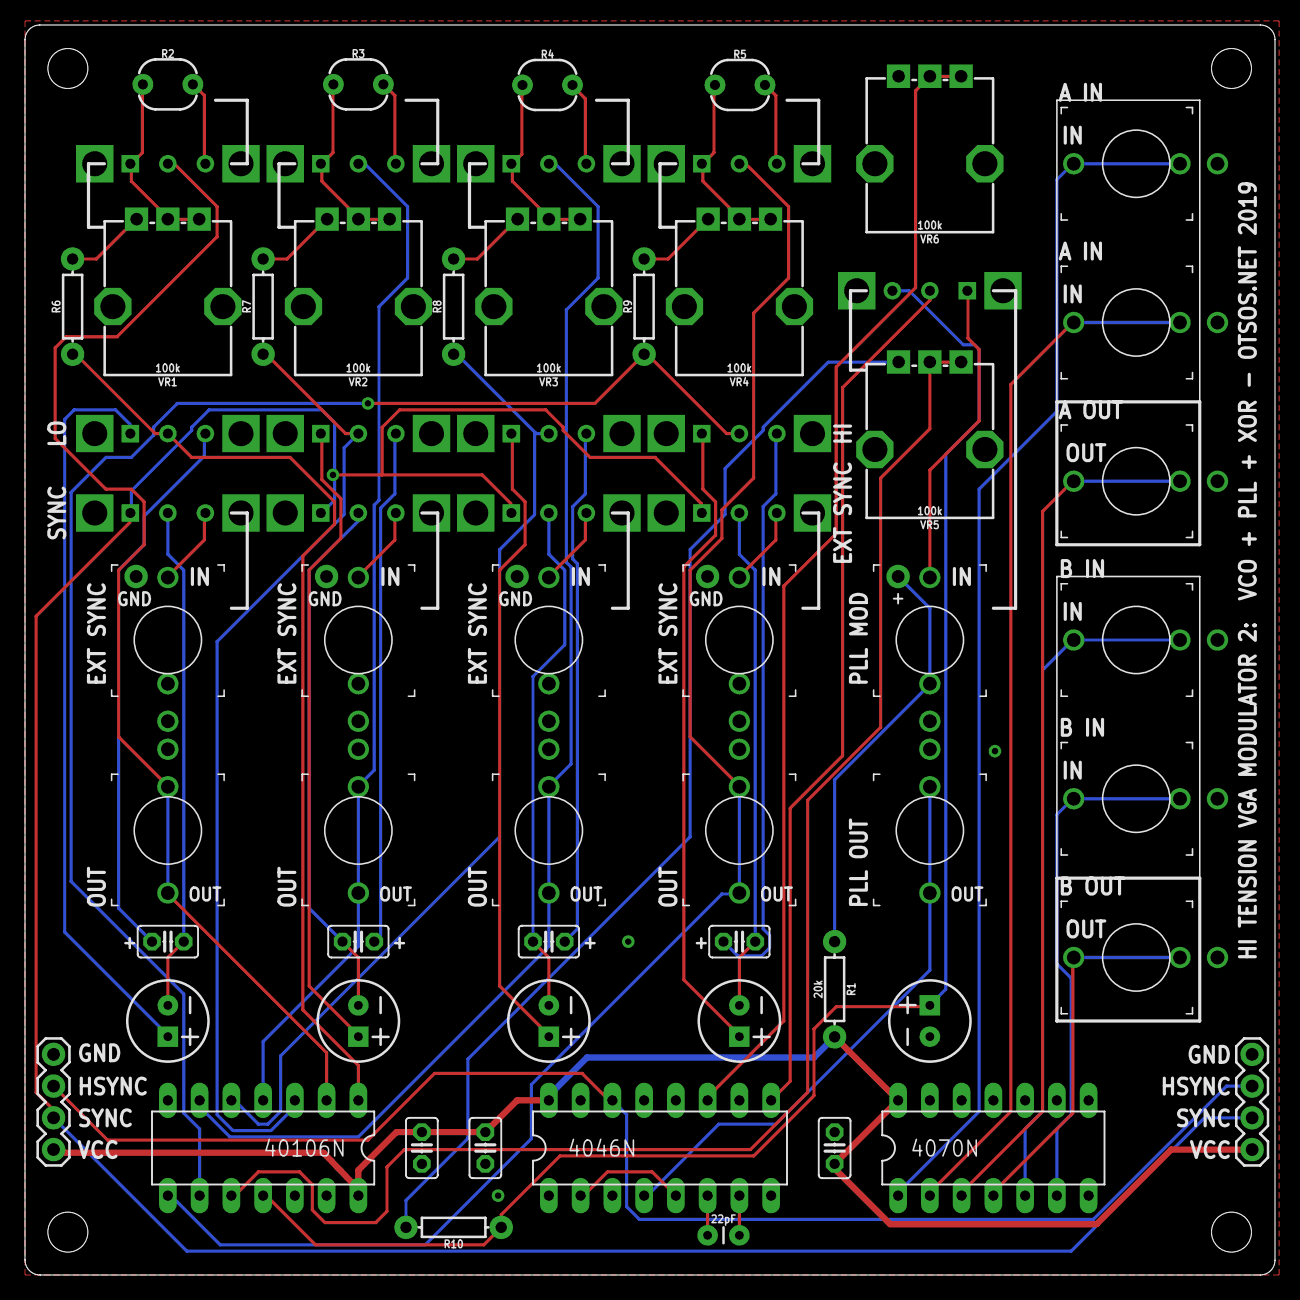
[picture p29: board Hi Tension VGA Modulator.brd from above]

Board: 2 copper layers, 100.0 x 100.0 mm, 72 parts (0 on the bottom side), 57 nets.

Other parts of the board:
U$1, U$2, U$3, U$4: MOUNTING_HOLE

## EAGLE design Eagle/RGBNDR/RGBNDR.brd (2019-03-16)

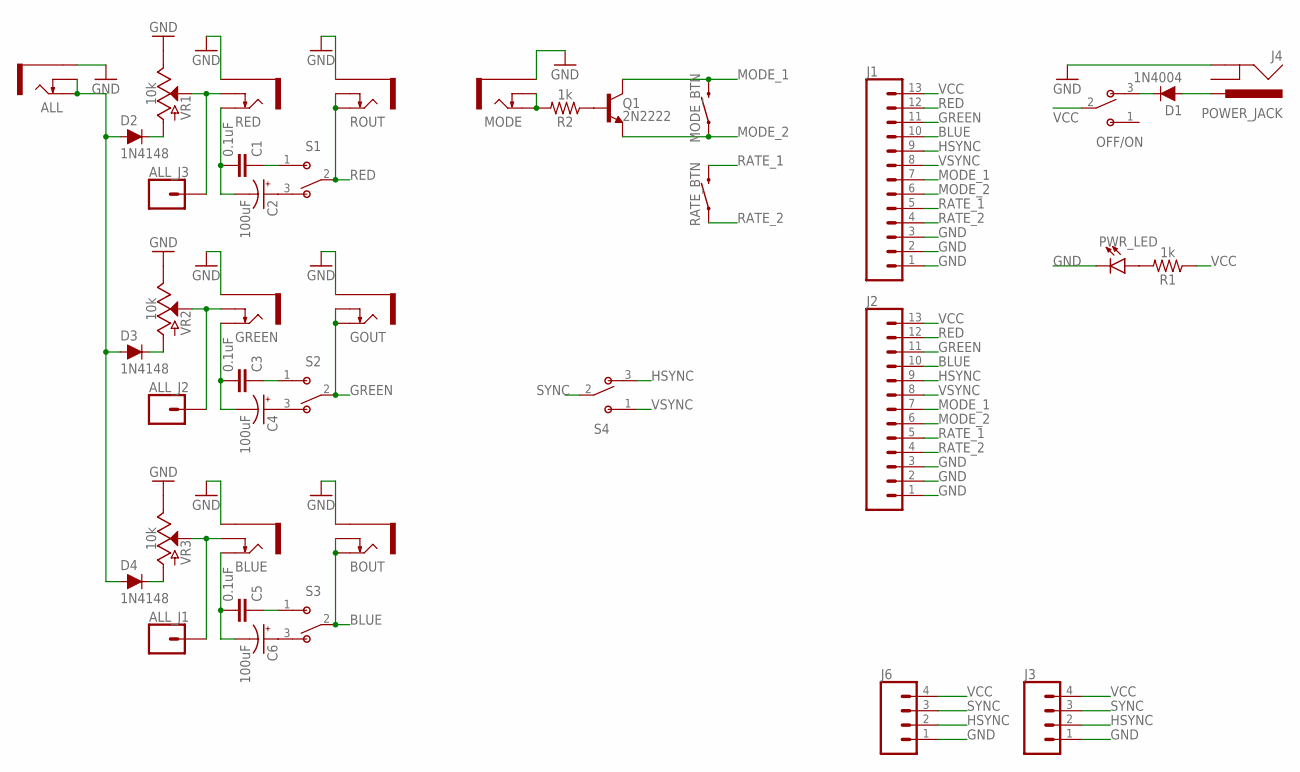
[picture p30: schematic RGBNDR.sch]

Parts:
ALL: THONKICONNNEW; WQP-PJ301M-12_JACK
ALL_J1, ALL_J2, ALL_J3: CONN_01PTH_NO_SILK_YES_STOP; 1X01_NO_SILK
BLUE: THONKICONNNEW; WQP-PJ301M-12_JACK
BOUT: THONKICONNNEW; WQP-PJ301M-12_JACK
C1, C3, C5: 0.1uF; C025-025X050
C2, C4, C6: 100uF; CPOL-RADIAL-2.5MM-6.5MM
D1: 1N4004; DIODE-1N4001
D2, D3, D4: 1N4148; DIODE-1N4148
GOUT: THONKICONNNEW; WQP-PJ301M-12_JACK
GREEN: THONKICONNNEW; WQP-PJ301M-12_JACK
J1, J2: CONN_13LONGPADS; 1X13-LONGPADS
J3, J6: CONN_04; 1X04
J4: POWER_JACK; POWER_JACK_PTH
MODE: THONKICONNNEW; WQP-PJ301M-12_JACK
MODE_BTN: MOMENTARY-SWITCH-SPST-PTH-6.0MM; TACTILE_SWITCH_PTH_6.0MM
OFF/ON: OS102011MS2QN1; SW_OS102011MS2QN1
PWR_LED: LED3MM; LED_3MM
Q1: 2N2222; TO-92
R1, R2: 1k; AXIAL-0.3
RATE_BTN: MOMENTARY-SWITCH-SPST-PTH-6.0MM; TACTILE_SWITCH_PTH_6.0MM
RED: THONKICONNNEW; WQP-PJ301M-12_JACK
ROUT: THONKICONNNEW; WQP-PJ301M-12_JACK
S1, S2, S3, S4: OS102011MS2QN1; SW_OS102011MS2QN1
VR1, VR2, VR3: 10k; POT-PTH-ALPS

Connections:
BLUE: BOUT.P$1_TIP (TIP), BOUT.P$2_SWITCH (SWITCH), J1.10, J2.10, S3.2
GND: ALL.P$3_SLEEVE (SLEEVE), BLUE.P$3_SLEEVE (SLEEVE), BOUT.P$3_SLEEVE (SLEEVE), GOUT.P$3_SLEEVE (SLEEVE), GREEN.P$3_SLEEVE (SLEEVE), J1.1, J1.2, J1.3, J2.1, J2.2, J2.3, J3.1, J4.GND, J6.1, MODE.P$3_SLEEVE (SLEEVE), PWR_LED.K (C), RED.P$3_SLEEVE (SLEEVE), ROUT.P$3_SLEEVE (SLEEVE), VR1.P$1 (E), VR2.P$1 (E), VR3.P$1 (E)
GREEN: GOUT.P$1_TIP (TIP), GOUT.P$2_SWITCH (SWITCH), J1.11, J2.11, S2.2
HSYNC: J1.9, J2.9, J3.2, J6.2, S4.3
MODE_1: J1.7, J2.7, MODE_BTN.3 (2), Q1.3 (C)
MODE_2: J1.6, J2.6, MODE_BTN.1, Q1.1 (E)
unnamed: ALL_J3.1, RED.P$2_SWITCH (SWITCH), VR1.P$2 (S)
unnamed: ALL_J2.1, GREEN.P$2_SWITCH (SWITCH), VR2.P$2 (S)
unnamed: ALL_J1.1, BLUE.P$2_SWITCH (SWITCH), VR3.P$2 (S)
unnamed: D1.A, J4.PWR
unnamed: D1.C, OFF/ON.3
unnamed: D2.C, VR1.P$3 (A)
unnamed: D3.C, VR2.P$3 (A)
unnamed: D4.C, VR3.P$3 (A)
unnamed: PWR_LED.A, R1.P$2 (2)
unnamed: MODE.P$1_TIP (TIP), MODE.P$2_SWITCH (SWITCH), R2.P$2 (2)
unnamed: C1.1, S1.1
unnamed: C2.1 (+), S1.3
unnamed: C1.2, C2.2 (-), RED.P$1_TIP (TIP)
unnamed: Q1.2 (B), R2.P$1 (1)
unnamed: C3.1, S2.1
unnamed: C4.1 (+), S2.3
unnamed: C3.2, C4.2 (-), GREEN.P$1_TIP (TIP)
unnamed: ALL.P$1_TIP (TIP), ALL.P$2_SWITCH (SWITCH), D2.A, D3.A, D4.A
unnamed: C5.1, S3.1
unnamed: C6.1 (+), S3.3
unnamed: BLUE.P$1_TIP (TIP), C5.2, C6.2 (-)
RATE_1: J1.5, J2.5, RATE_BTN.3 (2)
RATE_2: J1.4, J2.4, RATE_BTN.1
RED: J1.12, J2.12, ROUT.P$1_TIP (TIP), ROUT.P$2_SWITCH (SWITCH), S1.2
SYNC: J3.3, J6.3, S4.2
VCC: J1.13, J2.13, J3.4, J6.4, OFF/ON.2, R1.P$1 (1)
VSYNC: J1.8, J2.8, S4.1

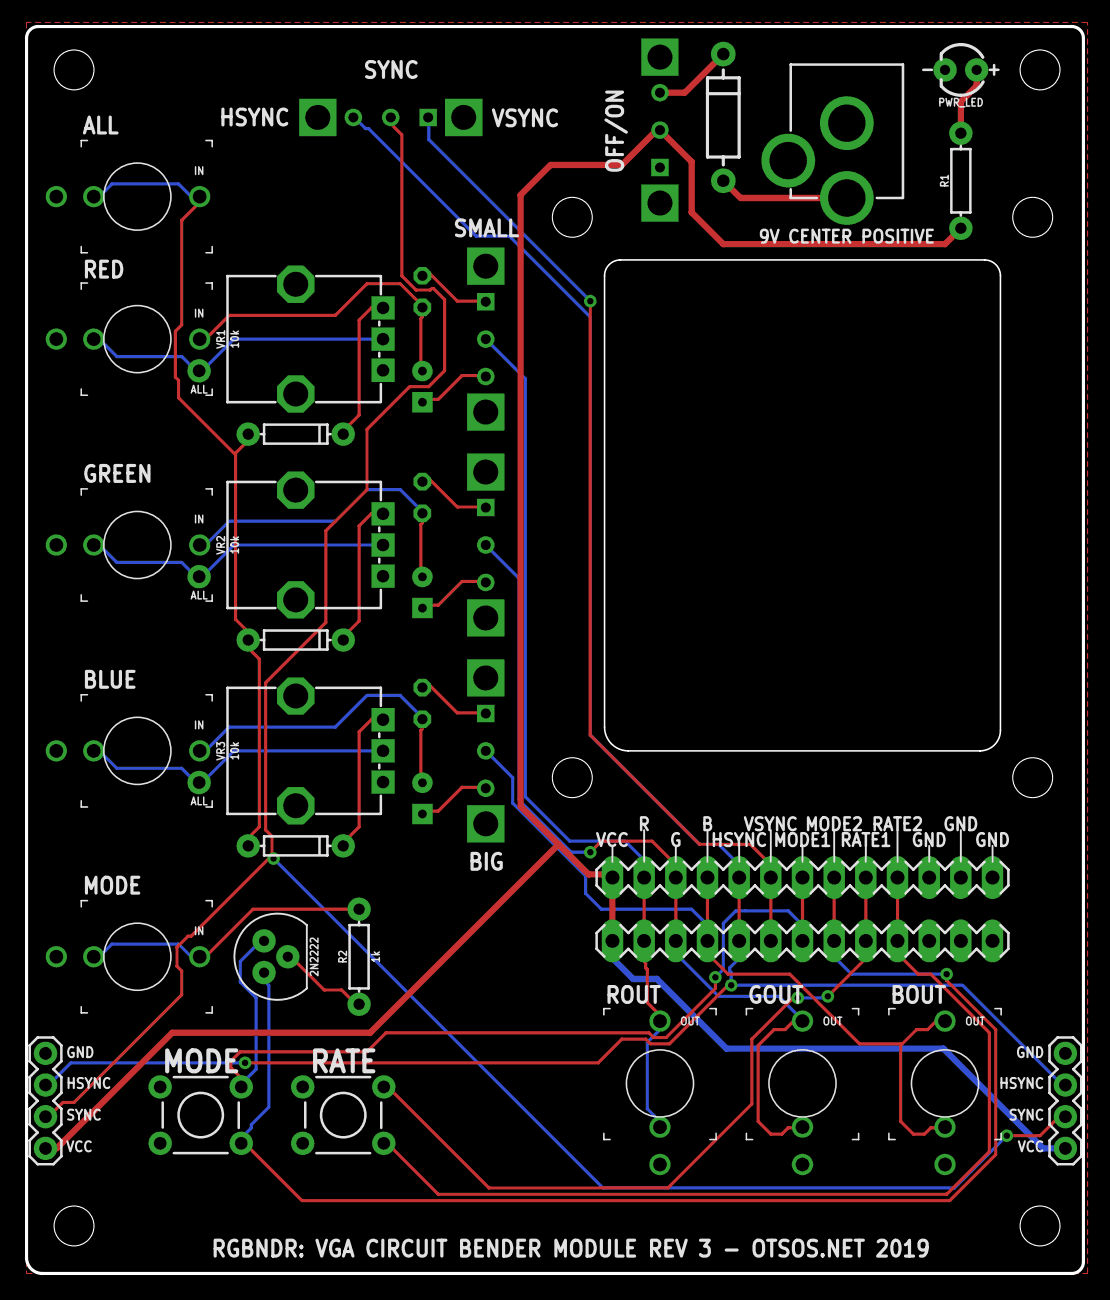
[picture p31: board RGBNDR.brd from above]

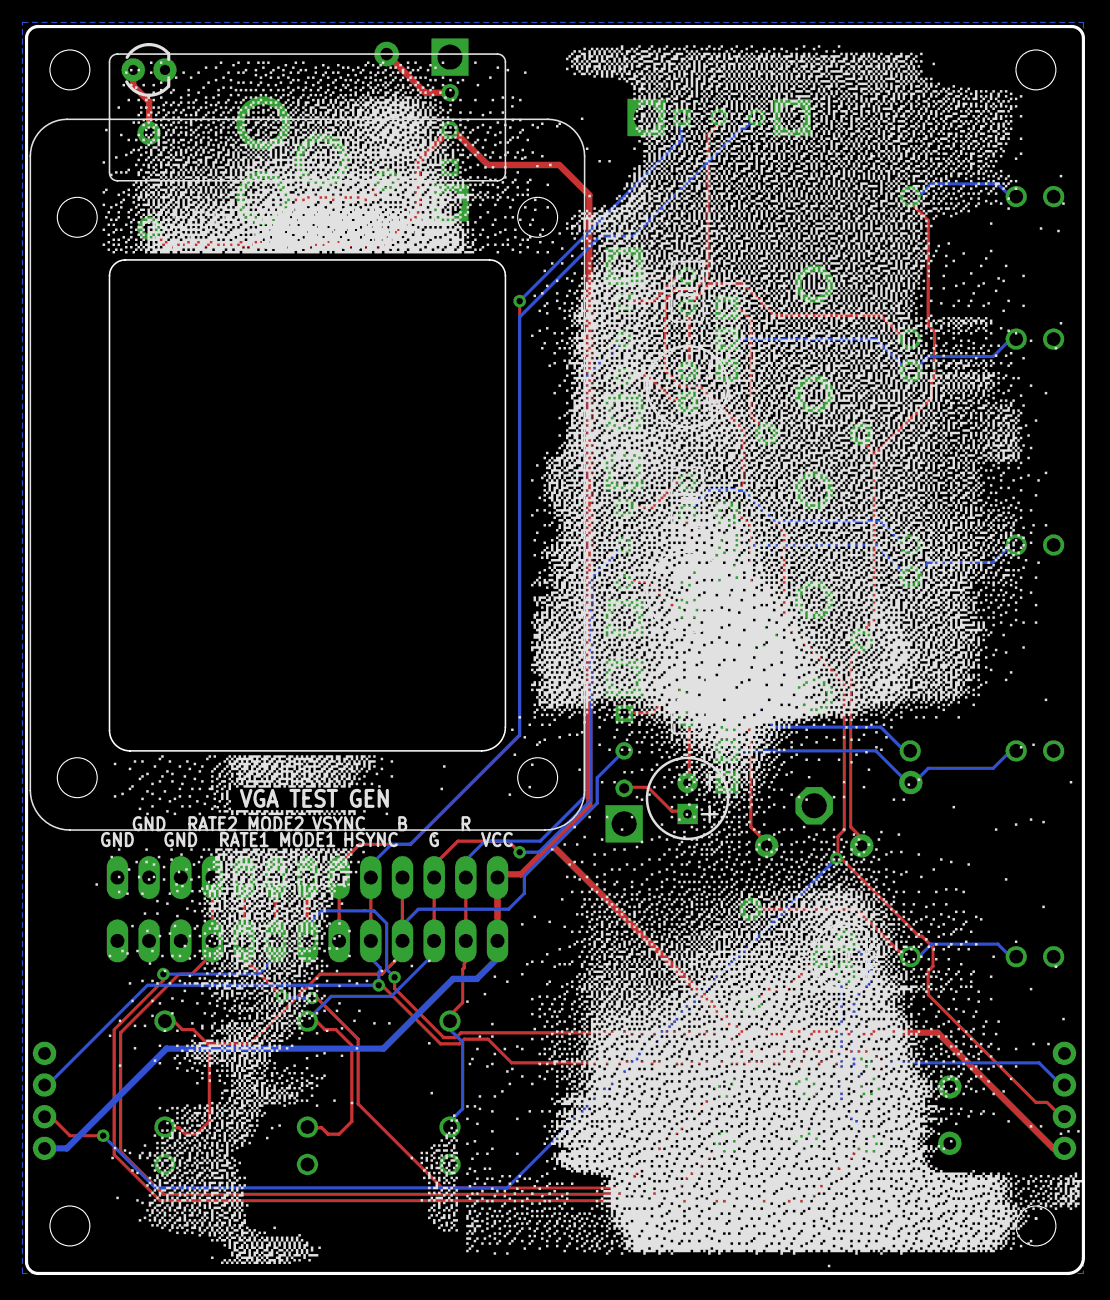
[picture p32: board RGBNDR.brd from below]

Board: 2 copper layers, 84.8 x 100.0 mm, 45 parts (8 on the bottom side), 33 nets.

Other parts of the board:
U$1: VGATESTGEN
U$2, U$3, U$4, U$5: MOUNTING_HOLE

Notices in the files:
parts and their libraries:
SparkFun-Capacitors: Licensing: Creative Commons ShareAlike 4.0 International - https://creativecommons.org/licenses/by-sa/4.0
